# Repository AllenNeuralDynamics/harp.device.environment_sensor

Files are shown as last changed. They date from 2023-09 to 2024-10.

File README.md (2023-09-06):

A self-contained, harp-compliant environment sensor

## Features
* pressure sensing
* temperature sensing
* humidity sensing
* USB powered
* Harp synchronization input

## Wiring Diagram
TODO

### Device Pinout
TODO

### Wiring Diagram
TODO

## Theory of Operation
TODO: awesome diagram {here}

## Harp Register Map
[List of Registers](./firmware/docs/register_map.csv)

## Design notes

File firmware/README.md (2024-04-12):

## Setting up the Build Environment

### Install Submodules
This project uses the [Harp Core RP2040](https://github.com/AllenNeuralDynamics/harp.core.rp2040) library as a submodule.
Install it with:
````
git submodule update --init
````

### Install Pico SDK
This project uses the [Pico SDK](https://github.com/raspberrypi/pico-sdk/tree/master).
The SDK needs to be downloaded and installed to a known folder on your PC.
Note that the PICO SDK also contains submodules (including TinyUSB), so you must ensure that they are also fetched with:
````
git clone git clone git@github.com:raspberrypi/pico-sdk.git
git submodule update --init --recursive
````

### Point to Pico SDK
Recommended, but optional: define the `PICO_SDK_PATH` environment variable to point to the location where the pico-sdk was downloaded. i.e:
````
PICO_SDK_PATH=/home/username/projects/pico-sdk
````
On Linux, it may be preferrable to put this in your `.bashrc` file.

## Compiling the Firmware

### Without an IDE
From this directory, create a directory called build, enter it, and invoke cmake with:
````
mkdir build
cd build
cmake ..
````
If you did not define the `PICO_SDK_PATH` as an environment variable, you must pass it in here like so:
````
mkdir build
cd build
cmake -DPICO_SDK_PATH=/path/to/pico-sdk ..
````
After this point, you can invoke the auto-generated Makefile with `make`

## Flashing the Firmware
Press-and-hold the Pico's BOOTSEL button and power it up (i.e: plug it into usb).
At this point you do one of the following:
* drag-and-drop the created **\*.uf2** file into the mass storage device that appears on your pc.
* flash with [picotool](https://github.com/raspberrypi/picotool)

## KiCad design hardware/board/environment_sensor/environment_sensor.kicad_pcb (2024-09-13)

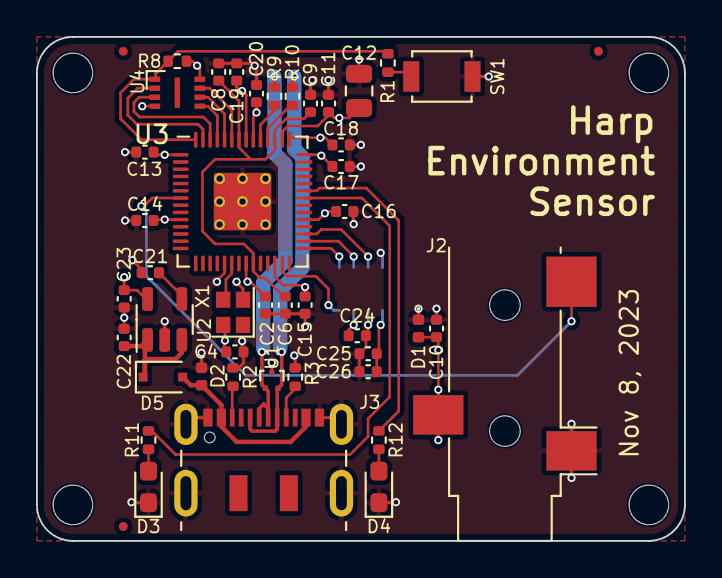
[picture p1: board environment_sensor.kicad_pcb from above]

Board: 4 copper layers, 36.0 x 28.0 mm, 47 parts (1 on the bottom side), 29 nets.

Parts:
C2, C6, C8, C13, C14, C15, C16, C17, C18, C19, C20, C24, C25: 100nF; C_0402_1005Metric
C4, C21: 10nF; C_0402_1005Metric
C9, C10, C11, C22, C26: 1uF; C_0402_1005Metric
C12: 10uF; C_0805_2012Metric
C23: 2.2uF; C_0402_1005Metric
D1, D2: D_TVS; D_0402_1005Metric
D3, D4: LED; LED_0603_1608Metric_Pad1.05x0.95mm_HandSolder
D5: BAT54J; D_SOD-323F
FID1, FID2, FID3: Fiducial; Fiducial_0.5mm_Mask1mm
J2: AudioJack3; Jack_3.5mm_CUI_SJ-3523-SMT_Horizontal
J3: USB_C_Receptacle_USB2.0; USB_C_Receptacle_JAE_DX07S016JA1R1500
R1: 1K; R_0402_1005Metric
R2, R3: 5K1; R_0402_1005Metric
R8: 10K; R_0402_1005Metric
R9, R10: 27; R_0402_1005Metric
R11, R12: 330; R_0402_1005Metric
SW1: SW_Push; SW_SPST_B3U-1000P
U1: TPD2EUSB30; Texas_DRT-3
U2: LP2985-3.3; SOT-23-5
U3: RP2040; RP2040-QFN-56
U4: W25Q16JVUXIQ; Winbond-8USON-2x3mm
U5: BME688; Bosch_LGA-8_3x3mm_P0.8mm_ClockwisePinNumbering
X1: ECS-TXO-2016; Crystal_SMD_2016-4Pin_2.0x1.6mm

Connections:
+1V1: C6.2, C8.2, C9.1, U3.23 (DVDD), U3.45 (VREG_VOUT), U3.50 (DVDD)
+3V3: C2.2, C4.2, C10.1, C11.1, C12.1, C13.2, C14.2, C15.2, C16.2, C17.2, C18.2, C19.2, C20.2, C23.2, C24.2, C25.2, C26.1, D1.2 (A2), J2.R, R8.2, U2.5 (VOUT), U3.1 (IOVDD), U3.10 (IOVDD), U3.22 (IOVDD), U3.26 (RUN), U3.33 (IOVDD), U3.42 (IOVDD), U3.43 (ADC_AVDD), U3.44 (VREG_IN), U3.48 (USB_VDD), U3.49 (IOVDD), U4.8 (VCC), U5.6 (VDDIO), U5.8 (VDD), X1.4 (VDD)
/Harp Core RP2040 + USB/CS: U3.31 (GPIO20), U5.2 (CSB)
/Harp Core RP2040 + USB/D+: J3.A6 (D+), J3.B6 (D+), R9.2, U1.1 (D+)
/Harp Core RP2040 + USB/D-: J3.A7 (D-), J3.B7 (D-), R10.2, U1.2 (D-)
/Harp Core RP2040 + USB/HARP_CLK_SYNC: J2.T, U3.7 (GPIO5)
/Harp Core RP2040 + USB/PICO: U3.30 (GPIO19), U5.3 (SDI)
/Harp Core RP2040 + USB/POCI: U3.27 (GPIO16), U5.5 (SDO)
/Harp Core RP2040 + USB/QSPI_CLK: U3.52 (QSPI_SCLK), U4.6 (CLK)
/Harp Core RP2040 + USB/QSPI_CS: R1.2, R8.1, U3.56 (QSPI_SS), U4.1 (~CS)
/Harp Core RP2040 + USB/QSPI_D0: U3.53 (QSPI_SD0), U4.5 (DI(IO0))
/Harp Core RP2040 + USB/QSPI_D1: U3.55 (QSPI_SD1), U4.2 (DO(IO1))
/Harp Core RP2040 + USB/QSPI_D2: U3.54 (QSPI_SD2), U4.3 (IO2)
/Harp Core RP2040 + USB/QSPI_D3: U3.51 (QSPI_SD3), U4.7 (IO3)
/Harp Core RP2040 + USB/SCK: U3.29 (GPIO18), U5.4 (SCK)
/Harp Core RP2040 + USB/USB_Boot: R1.1, SW1.2
GND: C2.1, C4.1, C6.1, C8.1, C9.2, C10.2, C11.2, C12.2, C13.1, C14.1, C15.1, C16.1, C17.1, C18.1, C19.1, C20.1, C21.2, C22.2, C23.1, C24.1, C25.1, C26.2, D1.1 (A1), D2.1 (A1), D3.1 (K), D4.1 (K), J2.S, J3.A1 (GND), J3.A12 (GND), J3.B1 (GND), J3.B12 (GND), J3.S1 (SHIELD), R2.2, R3.2, SW1.1, U1.3 (GND), U2.2 (GND), U3.19 (TESTEN), U3.57 (GND), U4.4 (GND), U5.1 (GND), U5.7 (GND), X1.2 (GND)
unnamed: D3.2 (A), R11.2
unnamed: D4.2 (A), R12.2
unnamed: J3.A5 (CC1), R2.1
unnamed: J3.B5 (CC2), R3.1
unnamed: C21.1, U2.4 (BP)
unnamed: R11.1, U3.36 (GPIO24)
unnamed: R12.1, U3.37 (GPIO25)
unnamed: R10.1, U3.46 (USB_DM)
unnamed: R9.1, U3.47 (USB_DP)
unnamed: U3.20 (XIN), X1.3 (OUT)
VBUS: D2.2 (A2), D5.2 (A), J3.A4 (VBUS), J3.A9 (VBUS), J3.B4 (VBUS), J3.B9 (VBUS)
VDD: C22.1, D5.1 (K), U2.1 (VIN), U2.3 (ON/~OFF)

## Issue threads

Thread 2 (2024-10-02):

1.0 PCB Self-Heating

Poofjunior, 2024-10-02:
The PCB has ~3 degrees C of self-heating.

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

Putting the PCB in an enclosure will make the effect worse.

The primary source of heat is likely the LDO regulator. (These are inherently inefficient because they burn off excess voltage as heat.) The next suspects are the LEDs (LEDs were blinking in this case) and then the MCU.

There are a few options here:
1. Move the sensor to the corner of the board
2. Add cutouts to the ground plane around the sensor to reduce sensitivity
3. Switch the LDO regulator for a switching regulator.
4. Lower the clock frequency of the MCU

>[!NOTE]
> It's worth confirming that the regulator is the problem using a thermal camera.

### Regulator Option

The RT6150B is a good candidate for a new power supply option. It is 90% efficient in the operating region we will use, and it's identical to what's used on the Pico 2 board. See [Pico 2 Datasheet](https://datasheets.raspberrypi.com/pico/pico-2-datasheet.pdf). It will cost more board space, though.

Poofjunior, 2024-10-03:
Update: Board has been redesigned with the following changes.

## Top
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
## Bottom
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

* added keepout regions for copper-poured features on all layers around the sensor to reduce heat transfer
* swapped linear regulator for a switching regulator that is 90% efficient
* moved the sensor to the corner of the board, further away from primary heat sources.
* increased PCB size to accommodate M3 mounting holes
* moved USB C connector and audio jack off of the board edge to account for case width.

Poofjunior, 2024-10-04:
Final board has an exposed thermal pad on the bottom:
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

Worst case: we can also put a heatsink on the RP2040 directly:
[Heatsink option](https://www.adafruit.com/product/1515)

Poofjunior, 2024-10-31:
V0.2.0 PCB self-heating looks a lot better. That's about 1-deg C of self-heating over 40ish minutes.

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

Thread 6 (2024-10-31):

Flesh out Arduino Serial Shim

patricklatimer, 2024-10-31:
The Adafruit driver for the BME680 is written for Arduino and calls various arduino-native functions. We've shimmed some of those in Arduino.h/cpp, but not the Serial class (print and println methods), as those methods have many type overloads so it's not as simple as just calling printf.

This doesn't affect normal operation, but if we wanted to use the BME680_DEBUG option to print debug info from the sensor, we'd need the shim.

Having this would also make it easier to use arduino libraries on other pico projects.

Here's an example of something that could probably be leveraged:
https://github.com/earlephilhower/ArduinoCore-API/blob/master/api/Print.h

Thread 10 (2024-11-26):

Add temp offset in firmware

patricklatimer, 2024-11-26:
The boards being tested seem to be around 5C too high. We should add a settable offset for each of the values into the firmware.

nathan-mars, 2025-01-14:
Joon is working on collecting validated temperature readings so we know what the offset should be, once we're able to set it in firmware.

Closed 2025-02-19.

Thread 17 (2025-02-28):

Move Environment Sensor BOOTSEL button to opposite side of PCB

Poofjunior, 2025-02-28:
With the BME688 on one side of the PCBA, and the remaining components on the other side, accessing the button once the device has been installed on a mounting point is not possible.

While we don't normally need access to this button once working firmware has been uploaded at least once, moving the button would give us the flexibility to flash the device without removing it from its installation location under any circumstance.

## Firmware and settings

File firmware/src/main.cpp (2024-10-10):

#include <pico/stdlib.h> // for uart printing
#include <cstring>
#include <stdio.h>
#include <config.h>
#include <pico/multicore.h>
#include <harp_c_app.h>
#include <harp_synchronizer.h>
#include <core_registers.h>
#include <reg_types.h>
#include "core1_sensor.h"

// Create device name array.
const uint16_t who_am_i = 1845;
const uint8_t hw_version_major = 1;
const uint8_t hw_version_minor = 0;
const uint8_t assembly_version = 2;
const uint8_t harp_version_major = 0;
const uint8_t harp_version_minor = 0;
const uint8_t fw_version_major = 0;
const uint8_t fw_version_minor = 1;
const uint16_t serial_number = ENV_SENSOR_DEVICE_ID;


void set_led_state(bool enabled)
{
    if (enabled)
    {
        gpio_init(LED_PIN);
        gpio_set_dir(LED_PIN, true); // true for output
        gpio_put(LED_PIN, 0);
    }
    else
        gpio_deinit(LED_PIN);
}


queue_t sensor_queue;
queue_t cmd_queue;

//////// Harp stuff

// Harp App Register Setup.
const size_t reg_count = 5;

// Define register contents.
#pragma pack(push, 1)
struct app_regs_t
{
    uint32_t pressure_pa;  // app register 0
    float temperature_c;         // app register 1
    float humidity_units;         // app register 2
    float pressure_temp_humidity[3];
    uint8_t enable_sensor_dispatch_events;
    // bool mute_harp_events; // harp.ismuted()?
} app_regs;
#pragma pack(pop)

// Define register "specs."
RegSpecs app_reg_specs[reg_count]
{
    {(uint8_t*)&app_regs.pressure_pa, sizeof(app_regs.pressure_pa), U32},
    {(uint8_t*)&app_regs.temperature_c, sizeof(app_regs.temperature_c), Float},
    {(uint8_t*)&app_regs.humidity_units, sizeof(app_regs.humidity_units), Float},
    {(uint8_t*)&app_regs.pressure_temp_humidity, sizeof(app_regs.pressure_temp_humidity), Float},
    {(uint8_t*)&app_regs.enable_sensor_dispatch_events, sizeof(app_regs.enable_sensor_dispatch_events), U8}
};

// Define register read-and-write handler functions.
RegFnPair reg_handler_fns[reg_count]
{
    {&HarpCore::read_reg_generic, &HarpCore::write_to_read_only_reg_error},
    {&HarpCore::read_reg_generic, &HarpCore::write_to_read_only_reg_error},
    {&HarpCore::read_reg_generic, &HarpCore::write_to_read_only_reg_error},
    {&HarpCore::read_reg_generic, &HarpCore::write_to_read_only_reg_error},
    {&HarpCore::read_reg_generic, &HarpCore::write_reg_generic},
};

void app_reset()
{
    app_regs.pressure_pa = 0;
    app_regs.temperature_c = 0;
    app_regs.humidity_units = 0;
    app_regs.pressure_temp_humidity[0] = 0;
    app_regs.pressure_temp_humidity[1] = 0;
    app_regs.pressure_temp_humidity[2] = 0;

    app_regs.enable_sensor_dispatch_events = 1;

    uint8_t reset = 0xff;
    queue_add_blocking(&cmd_queue,&reset);
}

void update_app_state()
{
    // Get data from sensor-reading loop via queue and set registers
    if (!queue_is_empty(&sensor_queue)){
        sensor_data_t data;
        queue_remove_blocking(&sensor_queue, &data);

        app_regs.pressure_pa = data.pressure_pa;
        app_regs.temperature_c = data.temperature_c;
        app_regs.humidity_units = data.humidity_units;
        app_regs.pressure_temp_humidity[0] = float(data.pressure_pa);
        app_regs.pressure_temp_humidity[1] = data.temperature_c;
        app_regs.pressure_temp_humidity[2] = data.humidity_units;
        
        // Send an event for the aggregate register
        if (!HarpCore::is_muted() && bool(app_regs.enable_sensor_dispatch_events))
            HarpCApp::send_harp_reply(EVENT, APP_REG_START_ADDRESS + 3);


    }

}

// Create Harp App.
HarpCApp& app = HarpCApp::init(who_am_i, hw_version_major, hw_version_minor,
                               assembly_version,
                               harp_version_major, harp_version_minor,
                               fw_version_major, fw_version_minor,
                               serial_number, "Env Sensor",
                               (const uint8_t*)GIT_HASH, // in CMakeLists.txt.
                               &app_regs, app_reg_specs,
                               reg_handler_fns, reg_count, update_app_state,
                               app_reset);



// Core0 main.
int main()
{
 

// Init Synchronizer.
    HarpSynchronizer& sync = HarpSynchronizer::init(HARP_SYNC_UART_ID,
                                                    HARP_SYNC_RX_PIN);
    // app.set_visual_indicators_fn(set_led_state);
    app.set_synchronizer(&sync);

    // launch core1 to read from the environment sensor
    bool core1_rslt = core1_setup();
    multicore_launch_core1(core1_main);

    // enable events by default
    app_regs.enable_sensor_dispatch_events = 1;

    while(true) {

        app.run();
        
    }
}

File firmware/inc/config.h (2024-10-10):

#ifndef CONFIG_H
#define CONFIG_H

#define TTL_PIN (23)
#define LED_PIN (24)
#define HARP_CORE_LED_PIN (25)

// #define DEBUG /////////

#define BME688_CS_PIN (20)
#define BME688_POCI_PIN (16)
#define BME688_PICO_PIN (19)
#define BME688_SCK_PIN (18)

#define HARP_SYNC_UART_ID (uart1)
#define HARP_SYNC_RX_PIN (5)

#define ENV_SENSOR_DEVICE_ID (0x057C) // 1404

#endif // CONFIG_H

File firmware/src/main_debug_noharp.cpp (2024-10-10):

#include <pico/stdlib.h> // for uart printing
#include <cstring>
#include <stdio.h>
#include <config.h>
#include <pico/stdio_usb.h>
#include <stdio.h>
#include "Adafruit_BME680_rpi.h"


void set_led_state(bool enabled)
{
    if (enabled)
    {
        gpio_init(LED_PIN);
        gpio_set_dir(LED_PIN, true); // true for output
        gpio_put(LED_PIN, 0);
    }
    else
        gpio_deinit(LED_PIN);
}

Adafruit_BME680 bme688(spi0,BME688_PICO_PIN,BME688_POCI_PIN,BME688_SCK_PIN,BME688_CS_PIN,true);

// copied from https://github.com/adafruit/Adafruit_BME680/blob/master/examples/bme680test/bme680test.ino
void loop(Adafruit_BME680& bme) {
  uint32_t ping = time_us_32();
  if (! bme.performReading()) {
    printf("Failed to perform reading :(\r\n");
    return;
  }
  uint32_t pong = time_us_32();
  uint32_t time = pong - ping;

  printf("Reading time = %lu us\r\n", time);

  printf("Temperature = %f *C\r\n", bme.temperature);

  printf("Pressure = %i Pa\r\n", bme.pressure);

  printf("Humidity = %f %\r\n", bme.humidity);

  printf("Gas = %f KOhms\r\n", bme.gas_resistance/1000.0);

  printf("\n");
  sleep_ms(2000);
}


// Core0 main.
int main()
{

  stdio_init_all();
  // Wait for serial port to open before continuing.
  // while (!stdio_usb_connected());
  sleep_ms(1000);
  printf("Hello, from an RP2040!\r\n");
  set_led_state(true);
  gpio_init(LED_PIN);
  gpio_init(HARP_CORE_LED_PIN);
  gpio_set_dir(HARP_CORE_LED_PIN, GPIO_OUT);
  sleep_ms(5000);
  gpio_put(LED_PIN, 1);
  sleep_ms(2000);
  printf("Hello, from an RP2040!\r\n");

  int8_t rslt = bme688.begin(0,true);

  while(true) {
    loop(bme688);
    gpio_put(LED_PIN, 1);
    gpio_put(HARP_CORE_LED_PIN, 0);
    sleep_ms(500);
    gpio_put(LED_PIN, 0);
    gpio_put(HARP_CORE_LED_PIN, 1);
    sleep_ms(500);
        
    }
}

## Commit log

2023-09-06 draft v0.1 pcb
    [environment_sensor.kicad_pcb, environment_sensor.kicad_sch, rp2040_with_usb.kicad_sch]
2023-11-07 update 3.5mm connector orientation and 3d models
    [environment_sensor.kicad_pcb, environment_sensor.kicad_sch, rp2040_with_usb.kicad_sch]
2024-04-12 flesh out environment sensor firmware
2024-09-13 Add bme68x driver and adapted Adafruit wrapper
2024-09-13 bugfix starting bytes written
    [environment_sensor.kicad_pcb]
2024-10-08 Integrate harp app/registers & read sensor from core1
2024-10-10 Fix reset behavior & empower enable_sensor_dispatch_events
    [main.cpp]
